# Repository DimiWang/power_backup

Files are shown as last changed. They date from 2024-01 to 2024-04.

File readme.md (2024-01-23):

# Power backup automation for 12V battery.
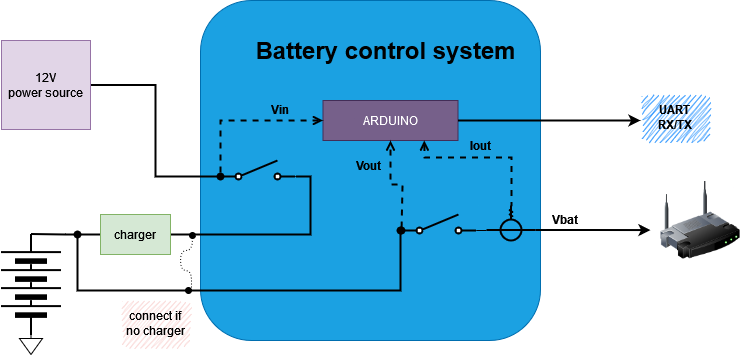
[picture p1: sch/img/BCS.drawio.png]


## Features:
* Fits on DIN rail.
* Power source circuit cut-off when no power
   (saves battery energy when power is not available)
* Measures battery real capacity
* Measures input voltage
* Battery cut-off when discharged
* LED signalisation
* Open collector signal on battery or power fail
* Output 5V max.100mA
* Output from battery
* Arduino pro mini
* Output bistable relay (for energy saving)

## Box enclosure
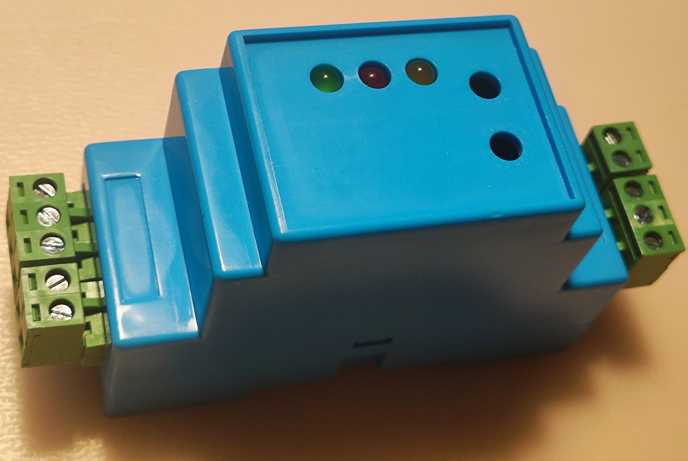
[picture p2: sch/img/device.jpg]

## Main Board
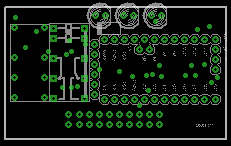
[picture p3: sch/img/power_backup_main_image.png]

## Main Board TOP layer
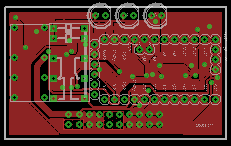
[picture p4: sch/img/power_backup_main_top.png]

## Main Board BOTTOM layer
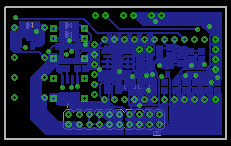
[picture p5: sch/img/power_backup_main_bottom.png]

## Main Board schematic
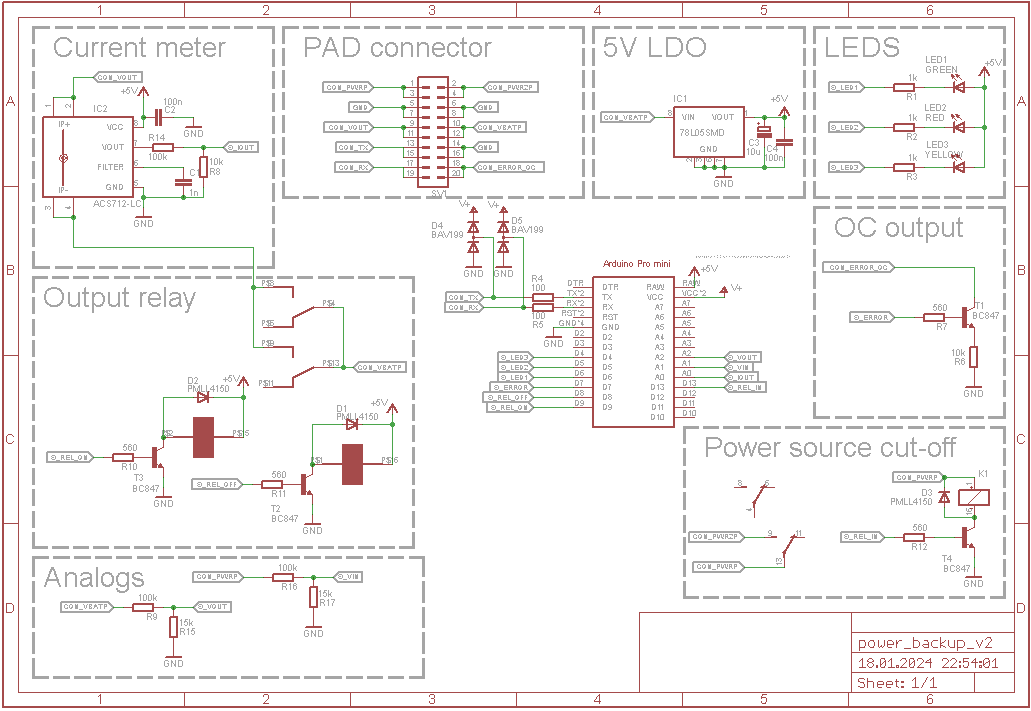
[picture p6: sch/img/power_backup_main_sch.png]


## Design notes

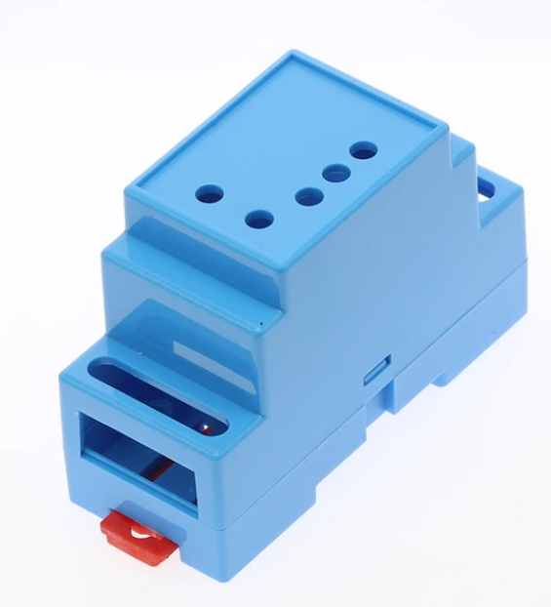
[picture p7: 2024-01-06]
sch/img/enclosure.png

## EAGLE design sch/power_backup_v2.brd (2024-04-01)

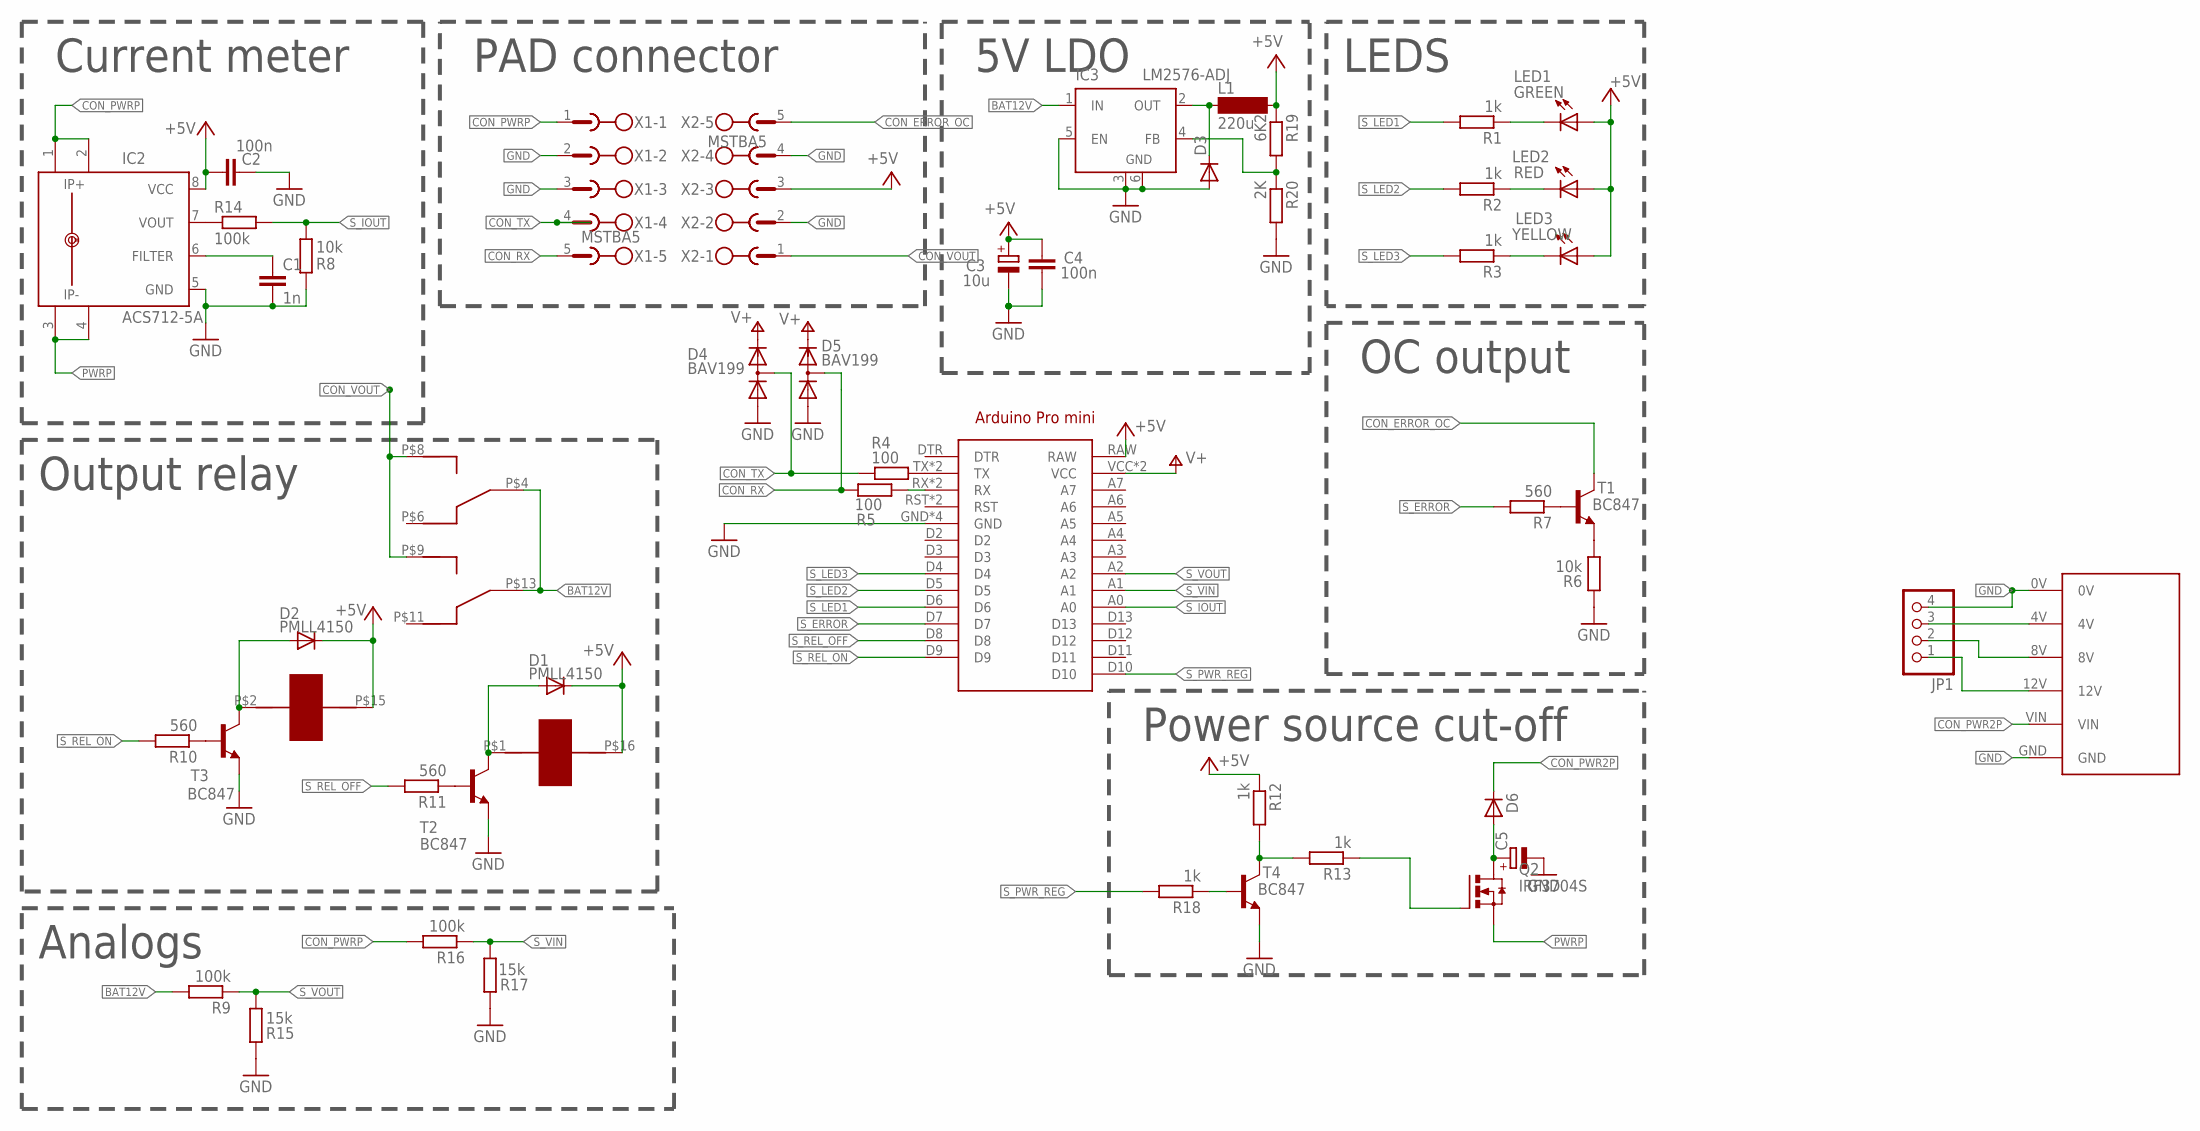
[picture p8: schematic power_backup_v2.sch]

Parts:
ARDUINO1: ARDUINO_PRO_MINI
C1: 1n; C0805
C2, C4: 100n; C0805
C3: 10u; SMC_C
C5: CPOL-EUE3.5-8; E3,5-8
D1, D2: PMLL4150; SOD80C
D3: DIODE-DO214AA; DO214AA
D4, D5: BAV199; SOT23
D6: DIODE_E-SMC; DIODE_SMC
IC2: ACS712-5A; SOIC8
IC3: LM2576-ADJ; TO263-5
JP1: PINHD-1X4; 1X04
K2: HFD2/003; RELAY
L1: 220u; MS85
LED1: GREEN; LED3MM
LED2: RED; LED3MM
LED3: YELLOW; LED3MM
Q2: IRF3704S; D2PACK
R1, R2, R3, R12, R13, R18: 1k; M0805
R4, R5: 100; M0805
R6, R8: 10k; M0805
R7, R10, R11: 560; M0805
R9, R14, R16: 100k; M0805
R15, R17: 15k; M0805
R19: 6K2; M0805
R20: 2K; M0805
T1, T2, T3, T4: BC847; SOT23
U$1: BALANCER
X1, X2: MSTBA5

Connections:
+5V: ARDUINO1.RAW, C2.1, C3.+, C4.1, D1.C, D2.C, IC2.8 (VCC), K2.P$15, K2.P$16, L1.2, LED1.A, LED2.A, LED3.A, R12.1, R19.1, X2.3
BAT4V: JP1.3, U$1.4V
BAT8V: JP1.2, U$1.8V
BAT12V: IC3.1 (IN), JP1.1, K2.P$4 (MID), K2.P$13 (MID), R9.2, U$1.12V
CON_ERROR_OC: T1.3 (C), X2.5
CON_PWR2P: D6.C (A), U$1.VIN
CON_PWRP: IC2.1 (IP+), IC2.2 (IP+1), R16.2, X1.1
CON_RX: D5.3 (AC), R5.1, X1.5
CON_TX: D4.3 (AC), R4.1, X1.4
CON_VOUT: K2.P$8 (NO), K2.P$9 (NO), X2.1
GND: ARDUINO1.GND, ARDUINO1.GND@1 (GND), ARDUINO1.GND@2 (GND), ARDUINO1.GND@3 (GND), C1.2, C2.2, C3.-, C4.2, C5.-, D3.A, D4.1 (A), D5.1 (A), IC2.5 (GND), IC3.3 (GND), IC3.5 (EN), IC3.6 (GND), JP1.4, R6.1, R8.2, R15.2, R17.2, R20.2, T2.2 (E), T3.2 (E), T4.2 (E), U$1.0V, U$1.GND, X1.2, X1.3, X2.2, X2.4
unnamed: LED1.K (C), R1.1
unnamed: LED2.K (C), R2.1
unnamed: LED3.K (C), R3.1
unnamed: C5.+, D6.A (C), Q2.2 (D)
unnamed: D1.A, K2.P$1, T2.3 (C)
unnamed: D2.A, K2.P$2, T3.3 (C)
unnamed: R10.1, T3.1 (B)
unnamed: R11.1, T2.1 (B)
unnamed: R12.2, R13.2, T4.3 (C)
unnamed: Q2.1 (G), R13.1
unnamed: C1.1, IC2.6 (FILTER)
unnamed: IC2.7 (VOUT), R14.1
unnamed: R7.1, T1.1 (B)
unnamed: R6.2, T1.2 (E)
unnamed: R18.1, T4.1 (B)
unnamed: ARDUINO1.TX, ARDUINO1.TX@1 (TX), R4.2
unnamed: ARDUINO1.RX, ARDUINO1.RX@1 (RX), R5.2
unnamed: D3.C, IC3.2 (OUT), L1.1
unnamed: IC3.4 (FB), R19.2, R20.1
PWRP: IC2.3 (IP-), IC2.4 (IP-1), Q2.3 (S)
S_ERROR: ARDUINO1.D7, R7.2
S_IOUT: ARDUINO1.A0, R8.1, R14.2
S_LED1: ARDUINO1.D6, R1.2
S_LED2: ARDUINO1.D5, R2.2
S_LED3: ARDUINO1.D4, R3.2
S_PWR_REG: ARDUINO1.D10, R18.2
S_REL_OFF: ARDUINO1.D8, R11.2
S_REL_ON: ARDUINO1.D9, R10.2
S_VIN: ARDUINO1.A1, R16.1, R17.1
S_VOUT: ARDUINO1.A2, R9.1, R15.1
V+: ARDUINO1.VCC, ARDUINO1.VCC@1 (VCC), D4.2 (C), D5.2 (C)

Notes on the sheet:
Output relay
Analogs
Current meter
PAD connector
LEDS
5V LDO
OC output
Power source cut-off

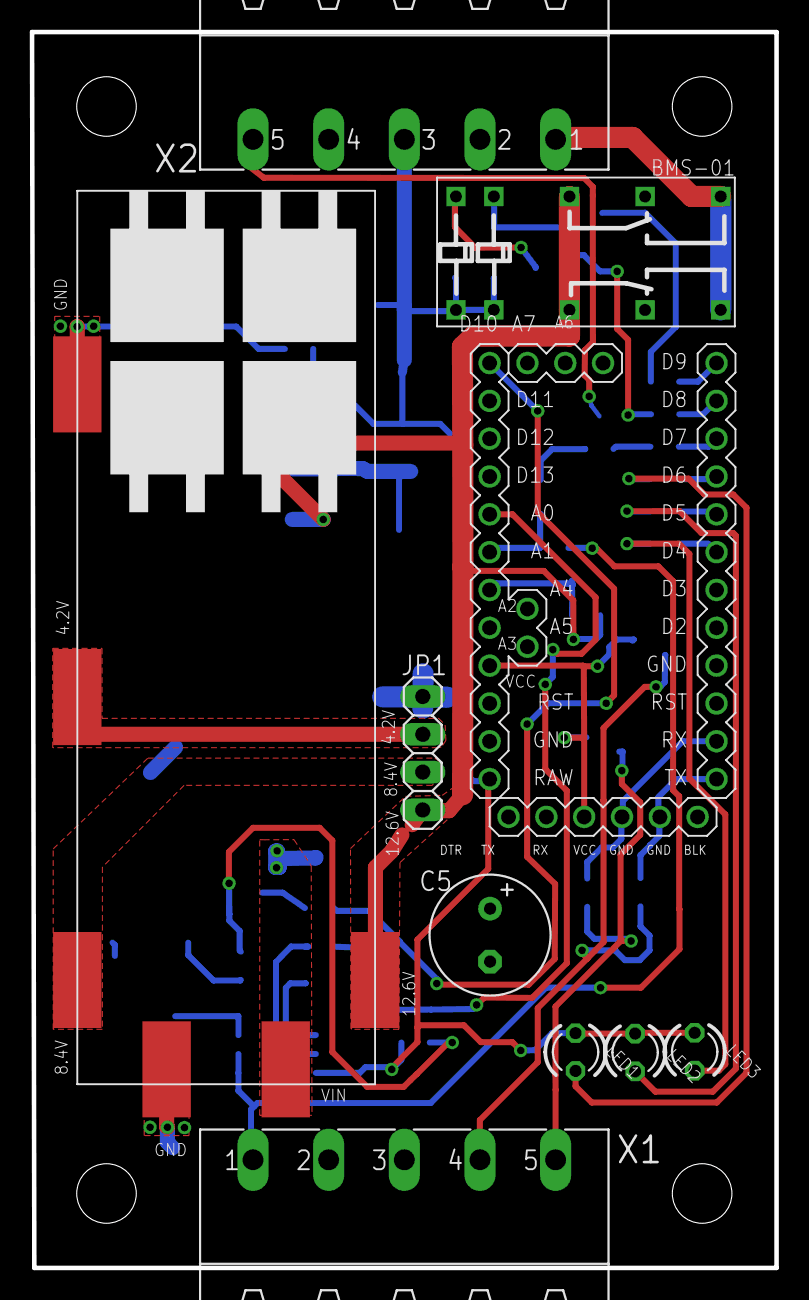
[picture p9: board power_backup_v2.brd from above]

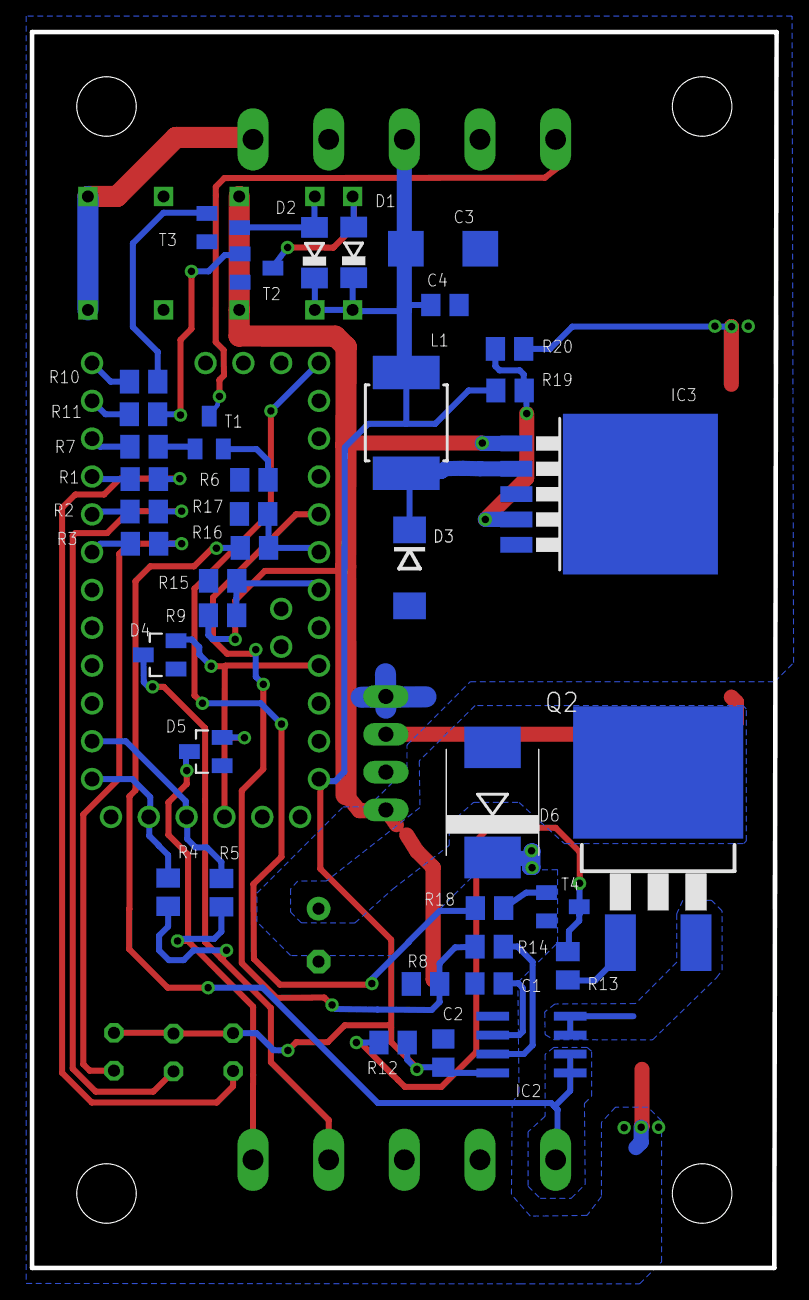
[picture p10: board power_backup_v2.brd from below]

Board: 2 copper layers, 50.0 x 83.0 mm, 48 parts (38 on the bottom side), 42 nets.

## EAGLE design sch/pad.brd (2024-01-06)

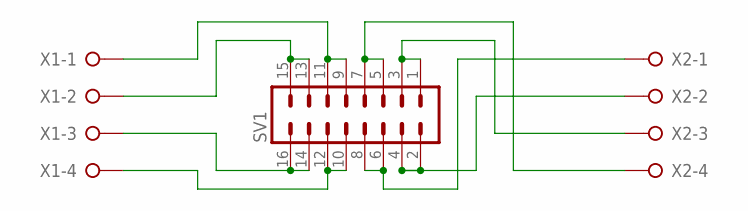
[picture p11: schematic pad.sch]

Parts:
SV1: MA08-2
X1, X2: W237-04P; W237-4P

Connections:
IN1: SV1.9, SV1.11, X1.1
IN2: SV1.13, SV1.15, X1.2
IN3: SV1.14, SV1.16, X1.3
IN4: SV1.10, SV1.12, X1.4
OUT1: SV1.6, SV1.8, X2.1
OUT2: SV1.2, SV1.4, X2.2
OUT3: SV1.1, SV1.3, X2.3
OUT4: SV1.5, SV1.7, X2.4

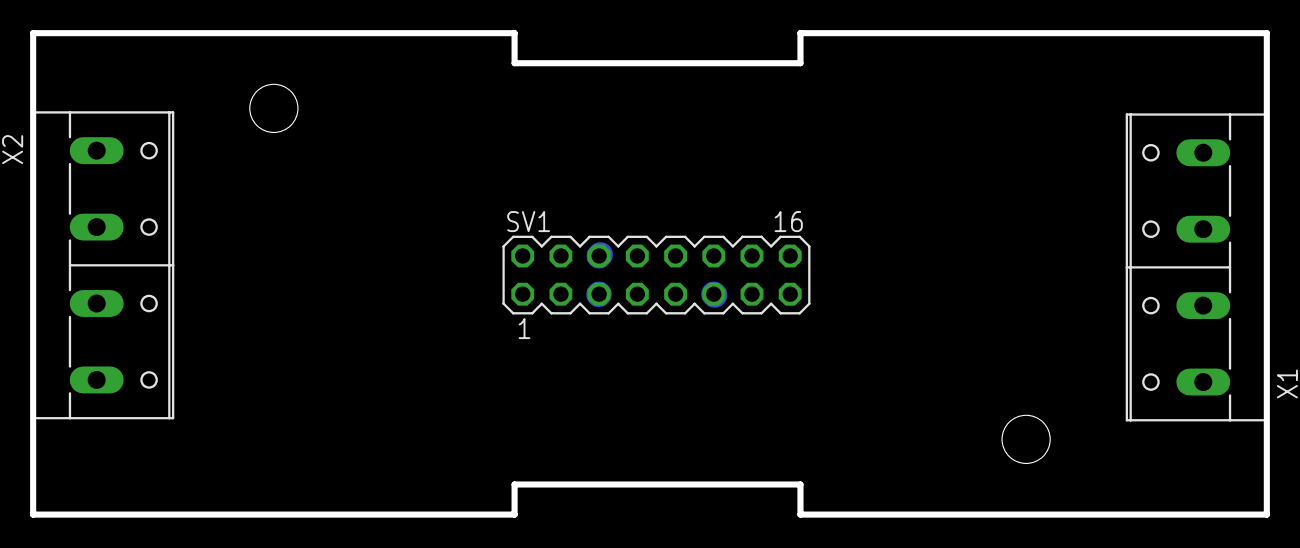
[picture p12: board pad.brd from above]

Board: 2 copper layers, 82.0 x 32.0 mm, 3 parts (0 on the bottom side), 8 nets.

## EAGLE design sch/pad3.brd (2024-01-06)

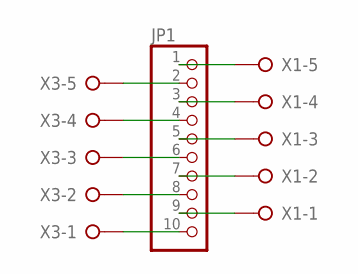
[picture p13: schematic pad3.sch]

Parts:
JP1: PINHD-1X10; 1X10
X1, X3: W237-05P; W237-5P

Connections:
unnamed: JP1.9, X1.1
unnamed: JP1.10, X3.1
unnamed: JP1.8, X3.2
unnamed: JP1.7, X1.2
unnamed: JP1.6, X3.3
unnamed: JP1.4, X3.4
unnamed: JP1.5, X1.3
unnamed: JP1.3, X1.4
unnamed: JP1.2, X3.5
unnamed: JP1.1, X1.5

Board: 2 copper layers, 3 parts (0 on the bottom side), 10 nets, no tracks yet.

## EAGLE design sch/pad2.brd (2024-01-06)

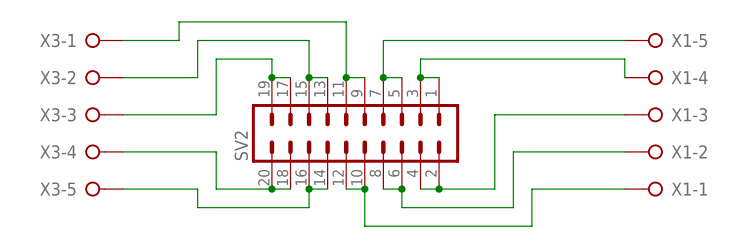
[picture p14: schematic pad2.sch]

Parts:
SV2: MA10-2
X1, X3: W237-05P; W237-5P

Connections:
IN1: SV2.13, SV2.15, X3.2
IN2: SV2.17, SV2.19, X3.3
IN3: SV2.18, SV2.20, X3.4
IN4: SV2.14, SV2.16, X3.5
unnamed: SV2.9, SV2.11, X3.1
unnamed: SV2.10, SV2.12, X1.1
OUT1: SV2.6, SV2.8, X1.2
OUT2: SV2.2, SV2.4, X1.3
OUT3: SV2.1, SV2.3, X1.4
OUT4: SV2.5, SV2.7, X1.5

Board: 2 copper layers, 3 parts (0 on the bottom side), 10 nets, no tracks yet.

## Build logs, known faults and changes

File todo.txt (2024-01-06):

ToDo:
1. Add documentation
2. Add code for arduino
3. Make a photo of complete device
4. add schematic PDF

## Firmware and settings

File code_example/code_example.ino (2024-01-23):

#define MIN_INPUT_VOLTAGE 11.5f /*V*/
#define MAX_INPUT_VOLTAGE 16.0f /*V*/
#define CUTOFF_VOLTAGE 10.0f    /*V*/
#define BATTERY_CAPACITY 5000   /*Ah*/

//digital
#define LED_YELLOW_PIN (6)
#define LED_GREEN_PIN (5)
#define LED_RED_PIN (4)
#define VOUT_REL_ON_PIN (9)
#define VOUT_REL_OFF_PIN (8)
#define OC_OUTPUT_PIN (7)
//analog
#define VOUT_ANALOG (2)
#define VIN_ANALOG (1)
#define IOUT_ANALOG (0)

#define MCU_VDD 3.3f /*mV*/
#define R1 15        /*k*/
#define R2 100       /*k*/

enum Led { GREEN_LED,
           YELLOW_LED,
           RED_LED };

enum AnalogValue { OUT_VOLTAGE,
                   IN_VOLTAGE,
                   OUT_CURRENT };

enum StateMachine {
  MEASURE,
  CONTROL,
  DELAY
};

#include <CircularBuffer.h>

unsigned long time = 0;

static CircularBuffer<float, 50> Vin_queue;
static CircularBuffer<float, 50> Vout_queue;
static CircularBuffer<float, 50> Iout_queue;


static float Vin;
static float Vout;
static float Iout;
static int step = MEASURE;
static bool input_voltage_present;
static float battery_capacity;
static bool output_on;

void setLedState(Led led, bool s) {
  const uint8_t leds[] = { LED_GREEN_PIN, LED_YELLOW_PIN, LED_RED_PIN };
  if (s == true) {
    pinMode(leds[led], OUTPUT);
    digitalWrite(leds[led], LOW);
  } else {
    pinMode(leds[led], INPUT);
  }
}

void setOutRelayOn(bool s) {
  if (s == true) {
    digitalWrite(VOUT_REL_ON_PIN, HIGH);
    delay(10);
    digitalWrite(VOUT_REL_ON_PIN, LOW);
  } else {
    digitalWrite(VOUT_REL_OFF_PIN, HIGH);
    delay(10);
    digitalWrite(VOUT_REL_OFF_PIN, LOW);
  }
}

float readAnalogValue(AnalogValue a_in) {
  float result;
  const float adc_res = (MCU_VDD / 1024);
  switch (a_in) {
    case OUT_VOLTAGE:
      result = (adc_res * (float)analogRead(VOUT_ANALOG) / R1) * (R1 + R2);
      break;
    case IN_VOLTAGE:
      result = (adc_res * (float)analogRead(VIN_ANALOG) / R1) * (R1 + R2);
      break;
    case OUT_CURRENT:
      result = 0;
      /*TBD*/
      break;
  }
  return result;
}


void calculateBatteryCapacity() {
  // TODO
}



// the setup function runs once when you press reset or power the board
void setup() {

  pinMode(LED_BUILTIN, INPUT);
  digitalWrite(LED_BUILTIN, LOW);
  pinMode(LED_YELLOW_PIN, INPUT);
  pinMode(LED_GREEN_PIN, INPUT);
  pinMode(LED_RED_PIN, INPUT);
  pinMode(VOUT_REL_ON_PIN, OUTPUT);
  pinMode(VOUT_REL_OFF_PIN, OUTPUT);
  pinMode(OC_OUTPUT_PIN, OUTPUT);
  Serial.begin(9600);
  output_on = false;
  time = millis();
}

// the loop function runs over and over again forever
void loop() {
  if (millis() - time >= 100) {
    time = millis();

    Vin = readAnalogValue(IN_VOLTAGE);
    Vout = readAnalogValue(OUT_VOLTAGE);
    Iout = readAnalogValue(IOUT_ANALOG);

    if (millis() - time >= 2000) {
      /*D*/ Serial.println(Vin);
      /*D*/ Serial.println(Vout);
      /*D*/ Serial.println(Iout);

      input_voltage_present = false;
      if (Vin > MIN_INPUT_VOLTAGE) {
        input_voltage_present = true;
      }
      if (!input_voltage_present && Vout < CUTOFF_VOLTAGE) {
        setOutRelayOn(false);
        output_on = false;
      } else if (!output_on) {
        setOutRelayOn(true);
        output_on = true;
        step = DELAY;
      }
      /* set staus leeds*/
      /* turn off relays*/
      /* count battery capacity*/
      /* detect battery output*/
      calculateBatteryCapacity();
    }
  }
}

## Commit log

2023-12-28 rename to pad and move terminals
    [power_backup.brd, power_backup.sch]
2024-01-06 PCBs first version ordered
    [pad.brd, pad.sch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]
2024-01-06 Board pictures and readme.md added
    [power_backup.GBL, power_backup.GBO, power_backup.GBP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]
2024-01-06 Enclosure image and schematic added
    [power_backup.sch]
2024-01-17 code example added
    [pad3.brd, pad3.sch, power_backup.brd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]
2024-01-17 updated device image
2024-01-18 updated images
    [power_backup_v2.brd, power_backup_v2.sch]
2024-04-01 version 2
    [power_backup_v2.brd, power_backup_v2.sch]
